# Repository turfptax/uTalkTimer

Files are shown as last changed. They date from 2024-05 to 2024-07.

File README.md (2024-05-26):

# uTalkTimer
uTalkTimer: An async ESPNOW-based MicroPython library for efficient discussion management in meetings, featuring speaker time tracking, speech queuing, and voting functionalities.

## Installation and Setup

Follow these instructions to set up the environment and install all required dependencies for the uTalkTimer project.

### Prerequisites

Before you begin, ensure you have MicroPython installed on your ESP32 device. You will also need to install `mpremote` to interact with your MicroPython device from your computer.

#### Installing mpremote

You can install `mpremote` using pip. Open your terminal and run:

```bash
pip install mpremote
```

### Installing Required Libraries

The project depends on the `aioespnow` and `ssd1306` libraries for asynchronous ESPNOW communication and OLED display management, respectively. Follow the steps below to install these libraries on your MicroPython device.

1. **Connect to Your MicroPython Device**:

   First, make sure to close any active IDE connections to the ESP32 micropython device:

   ```bash
   mpremote mip install aioespnow
   mpremote mip install ssd1306
   ```

2. **Verify Libraries**:

   Use thonny or another IDE to varify that the two files are stored in a 'lib' directory with the .mpy extension:

   ```bash
   lib
       aioespnow.mpy
       ssd1306.mpy
   ```
You should see `aioespnow.mpy` and `ssd1306.mpy` listed.

3. **Transfer the following files to your device**:

- boot.py
- freesans20.py (for larger font support)
- writer.py (required for rendering freesans20)

### Verifying the Installation

After installing the libraries, you can check if they are correctly placed by listing the files in the `/lib` directory on your device by trying to import the libraries:

```bash
import aioespnow
import ssd1306
```

## Running the Project

Once all prerequisites and required libraries are installed, you can upload power on the device:
Project runs on the boot.py at boot

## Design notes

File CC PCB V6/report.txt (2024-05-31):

Exported 'G:\TTXONE\OneDrive - TURFPTAx\Documents\0 GH\uTalkTimer\CC PCB V6\ThinkTankTimerVote-F_Silkscreen.svg'.
Exported 'G:\TTXONE\OneDrive - TURFPTAx\Documents\0 GH\uTalkTimer\CC PCB V6\ThinkTankTimerVote-Edge_Cuts.svg'.

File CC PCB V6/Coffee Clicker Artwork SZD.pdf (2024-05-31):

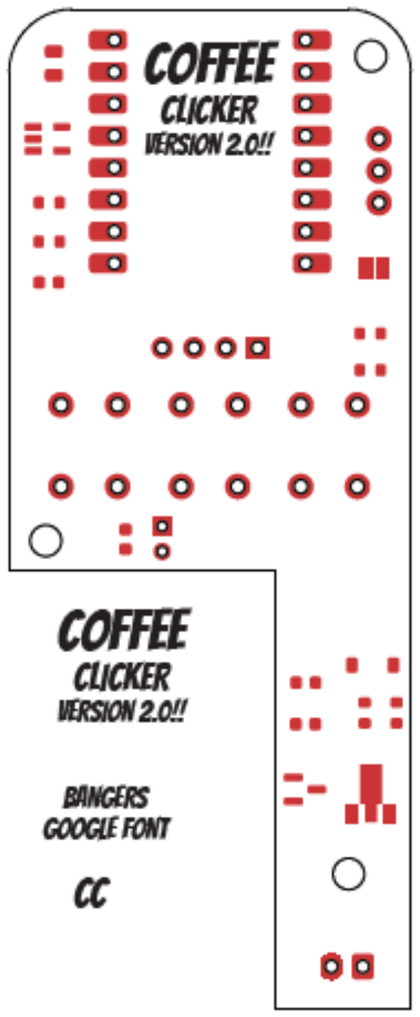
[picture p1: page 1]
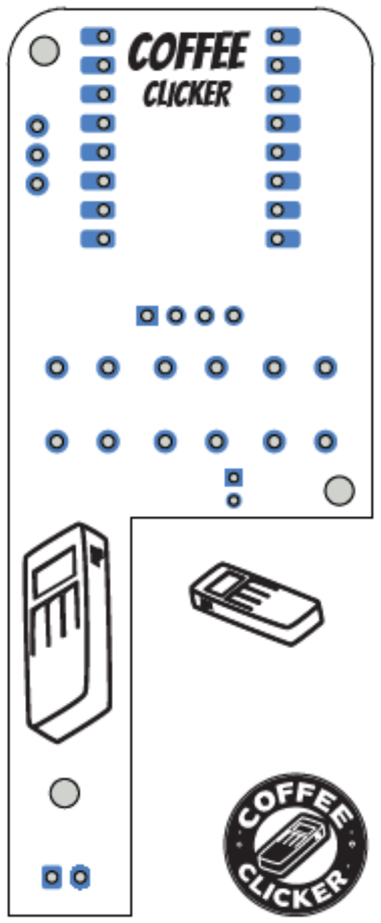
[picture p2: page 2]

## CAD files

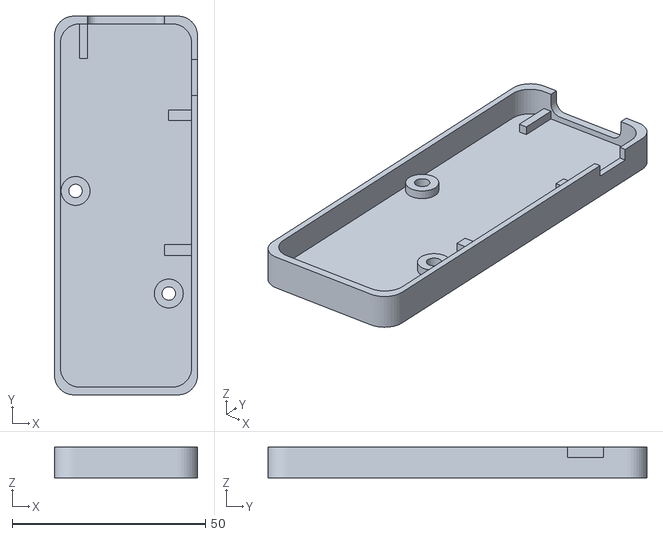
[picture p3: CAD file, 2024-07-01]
STL Case Files/BottomCaseV6.stl
37.0 x 98.0 x 8.00

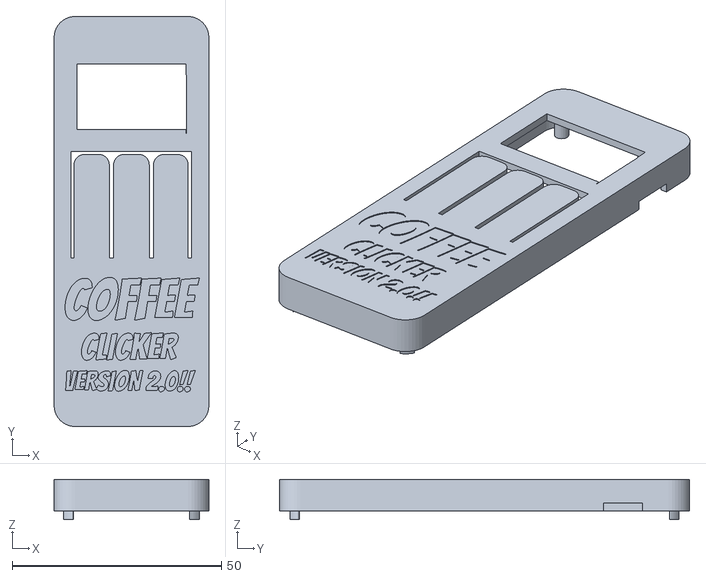
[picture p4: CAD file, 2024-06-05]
STL Case Files/TopCaseV6.stl
37.0 x 98.0 x 9.60

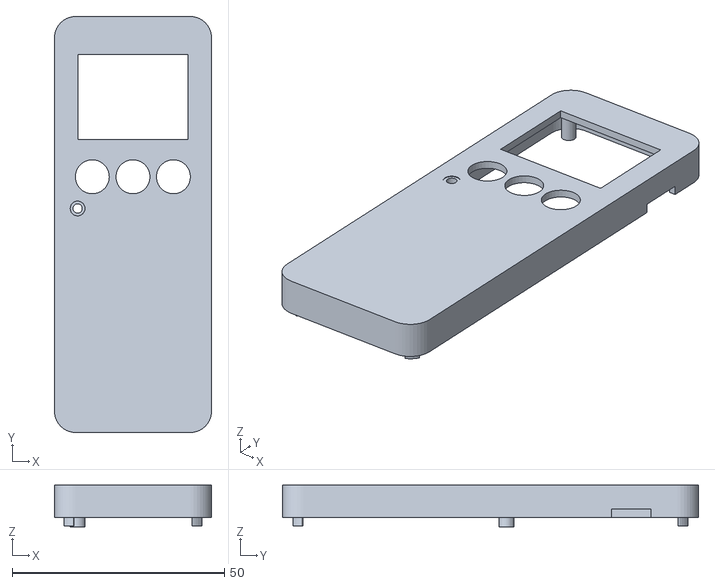
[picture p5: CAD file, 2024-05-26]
STL Case Files/TopCaseV5-Holder.stl
37.0 x 98.0 x 9.80

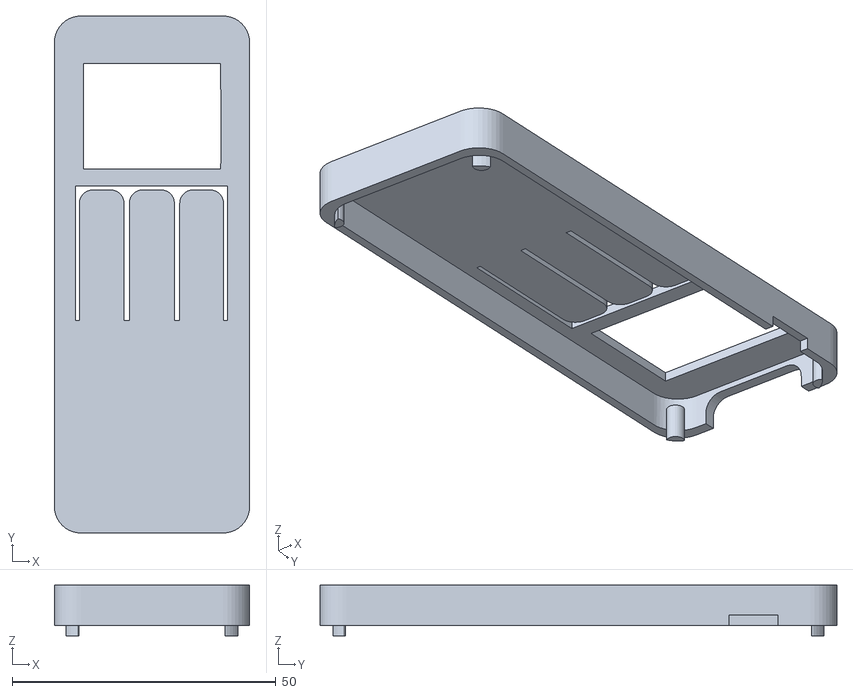
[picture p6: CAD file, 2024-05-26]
STL Case Files/TopCaseV5-Final.stl
37.0 x 98.0 x 9.60

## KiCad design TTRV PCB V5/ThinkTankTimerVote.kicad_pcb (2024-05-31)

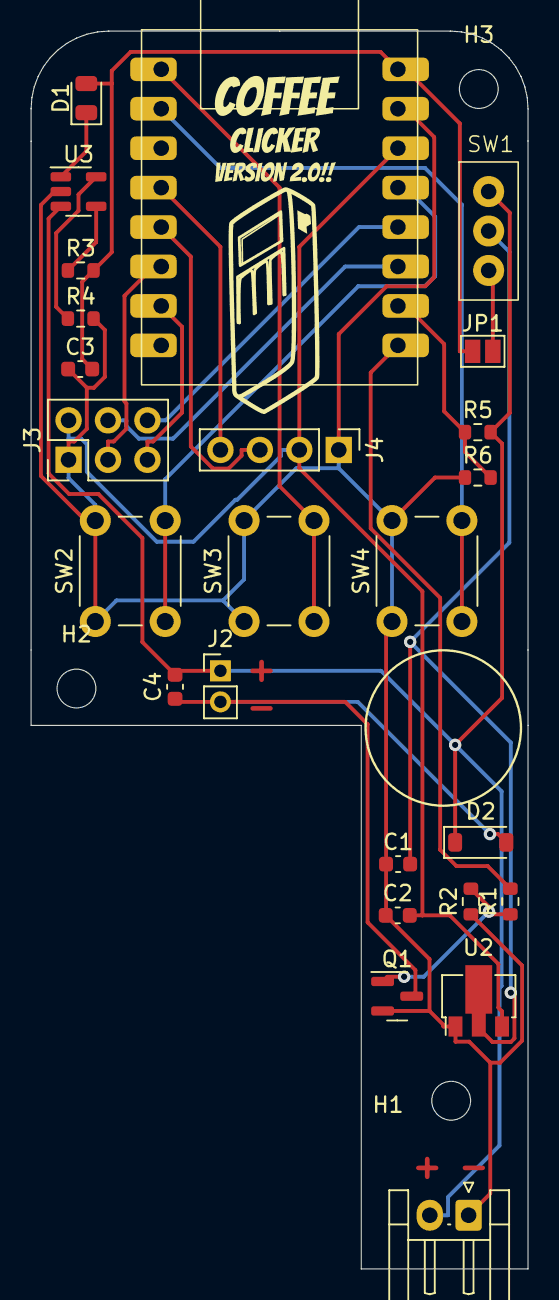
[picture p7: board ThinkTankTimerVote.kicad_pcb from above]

Board: 2 copper layers, 32.0 x 79.7 mm, 28 parts (0 on the bottom side), 22 nets.

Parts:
C1, C2, C3: 2.2 uF; C_0603_1608Metric
C4: 100 uF; C_0603_1608Metric
D1: LED GREEN; LED_0805_2012Metric
D2: 1N4007; D_SOD-123
H1, H2, H3: MountingHole; MountingHole_2.5mm
J1: BattLeft; JST_EH_S2B-EH_1x02_P2.50mm_Horizontal
J2: Conn_01x02; PinHeader_1x02_P2.00mm_Vertical
J3: Conn_02x03_Odd_Even; PinHeader_2x03_P2.54mm_Vertical
J4: Conn_01x04; PinHeader_1x04_P2.54mm_Vertical
JP1: 5V Jump; SolderJumper-2_P1.3mm_Open_Pad1.0x1.5mm
Q1: IRLML2060; SOT-23
R1, R2, R5: 10k; R_0603_1608Metric
R3: 2k; R_0603_1608Metric
R4: 2.7k; R_0603_1608Metric
R6: 20k; R_0603_1608Metric
SW1: SW_DPDT_x2; Switch3Pin
SW2, SW3, SW4: SW_Push; SW_PUSH_6mm_H7.3mm
U1: ESP32-C3-Super Mini
U2: HT75xx-1-SOT89; SOT-89-3
U3: LTC4054ES5-4.2; TSOT-23-5

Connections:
+3V3: C2.2, J3.2, J4.2, U1.102 (3V3), U2.3 (VOUT)
+5V: C3.2, D1.2 (A), JP1.1 (A), R3.2, U1.100 (5V)
ADC1_BAT: R5.1, R6.2, U1.1 (GPIO1)
ADC2: J3.4, U1.2 (GPIO2)
ADC3: J3.6, U1.3 (GPIO3)
Batt+: C4.2, D2.1 (K), J1.2, J2.1, R5.2, SW1.1 (A), U3.3 (BAT)
GND: C1.1, C2.1, C3.1, J1.1, J3.1, J4.1, Q1.2 (S), R2.1, R4.2, R6.1, SW2.1, SW3.1, SW4.1, U1.101 (GND), U2.1 (GND), U3.2 (GND)
GPIO10: J3.3, U1.10 (GPIO10)
GPIO20: J3.5, U1.20 (GPIO20)
Left: SW2.2, U1.4 (GPIO4)
Middle: SW3.2, U1.5 (GPIO5)
MotSig: R1.2, U1.0 (GPIO0)
Motor-: C4.1, D2.2 (A), J2.2, Q1.3 (D)
unnamed: D1.1 (K), U3.1 (~CHRG)
unnamed: JP1.2 (B), SW1.3 (C)
unnamed: Q1.1 (G), R1.1, R2.2
unnamed: R4.1, U3.5 (PROG)
unnamed: R3.1, U3.4 (V_{CC})
Right: SW4.2, U1.6 (GPIO6)
SCL: J4.3, U1.9 (GPIO9)
SDA: J4.4, U1.8 (GPIO8)
VILDO: C1.2, SW1.2 (B), U2.2 (VIN)

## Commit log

2024-05-01 Create boot.py
    Main program using async. Current uTT is the remote testing device.
2024-05-25 Update boot.py - added timer
    Added timer tracking and boot time
    data stored in time_markers global.
2024-05-25 Update boot.py
    Configuring communication protocol for ad-hoc espnow between two devices.
2024-05-26 Update boot.py
    - Fixed interrupt debounce
    - Included writer.py and freesans20.py (larger fonts)
2024-05-26 Main Files
    PCB, STLs, and KiCad Files
    [ThinkTankTimerVote-B_Cu.gbr, ThinkTankTimerVote-B_Mask.gbr, ThinkTankTimerVote-B_Paste.gbr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]
2024-05-30 Update PCB
    [ThinkTankTimerVote.kicad_pcb, ThinkTankTimerVote.kicad_sch]
2024-05-31 PCB Update
    Includes Artwork and Rough Draft KiCad Files
    [ThinkTankTimerVote.kicad_pcb]
2024-05-31 PCB V 2.6.0
    [ThinkTankTimerVote-B_Cu.gbr, ThinkTankTimerVote-B_Mask.gbr, ThinkTankTimerVote-B_Paste.gbr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]
2024-06-05 PCB6 Micropython Pin Updates
    # Included battery level indicator
    [TopCaseV6.stl]
2024-07-01 v2.1 updates
    [BottomCaseV6.stl, ThinkTankTimerVote.kicad_sch]
